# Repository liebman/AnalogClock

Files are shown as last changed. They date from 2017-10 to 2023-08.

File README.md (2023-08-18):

# AnalogClock 2.X

Project to sync analog clocks to a few milliseconds using NTP for time synchronization. Details of operation can be found in this [blog post](https://blog.taboola.com/analog-clocks-ntp/)



[I2CAnalogClock](I2CAnalogClock) contains the code for the ATTiny85 as an I2C based Analog Clock controller.  I am now using [PlatformIO](https://platformio.org/) for development.

[SynchroClock](SynchroClock) contains the code for the ESP8266 module.   I am now using [PlatformIO](https://platformio.org/) for development.

[NTPTest](NTPTest) contains a framework for testing the NTP class in an accelerated manor on linux or MacOS saving days of waiting for results.

[eagle](eagle) contains the [Eagle](https://www.autodesk.com/products/eagle/overview) design files and the BOM.

## Features

* Automatic daylight saving time adjustments
* Clock position & configuration saved on power fail
* Low power consumption: approx. 0.25ma in early testing
* adjustable tick/adjust pulse width/duty cycle/delay should support most one second "tick" (non-sweep) clocks.
* NTP implementation computes drift and uses that to increase accuricy between NTP updates

## Configuration

   When the clock is initially powered on it creates a wifi captive portal.  It will show up in the list of available wifi networks as SynchroClockXXXXXXX (where the X’s are some number).  Configuration mode can be forced by holding down the reset button until the LED is turns on and stays on for at least 2 seconds then releasing it. NOTE that if you conrinue holding the reset button for more than 10 seconds the LED will go back off initiating a factory reset to default settings. When you connect to this you are given a menu that lets you set many configuration options:

* Wifi Network (SSID)
* Wifi Network password
* Clock Position - enter the current time shown on the clock as HH:MM:SS.
* NTP Server to sync with
* 1st time change as 6 fields (US/Pacific would be: 2 0 0 3 2 -25200 meaning the second Sunday in March at 2am we change to UTC-7 hours, and Israel: -1 0 -2 3 2 10800 meaning the Friday before the last Sunday of in March at 2am we change to UTC+3)
  * occurrence - 2 would be the second occurrence of the day of week specified, -1 would be the last one.
  * day of week - where 0 = Sunday
  * days offset - +|- days, used for "the Friday before the last Sunday"
  * month - where 1 = January
  * hour - where 0 = midnight
  * time offset - this is the offset in seconds from UTC
* 2nd time change as 5 fields as described above (US/Pacific: 1 0 0 11 2 -28800 meaning the first Sunday in November at 2am we change to UTC-8 hours, and Israel: -1 0 0 10 2 7200 meaning the last Sunday of October we change to UTC-2)

Advanced options:

* Stay Awake - when set true the ESP8266 will not use deep sleep and will run a small web servers allowing various operations to be performed with an http interface.
* Tick Pulse - this is the duration in milliseconds of the “tick”.
* Tick Duty Cycle - the percentage of time that the tick is on using PWM
* Adjust Start Pulse - this uis the duration in milliseconds of the initial pulse of an adjustment
* Adjust Pulse - this is the duration in milliseconds of the “tick” used to advance the clock rapidly.
* Adjust Duty Cycle - the percentage of time that the tick is on using PWM
* Adjust Delay - this is the delay in milliseconds between “ticks” when advancing the clock rapidly.
* Network Logger Host - (optional) hostname to send log lines to.
* Network Logger Port - (optional) tcp port to send log lines to.
* Clear NTP Persist - when set 'true' clears any saved adjustments and drift calculations.

## Schematic

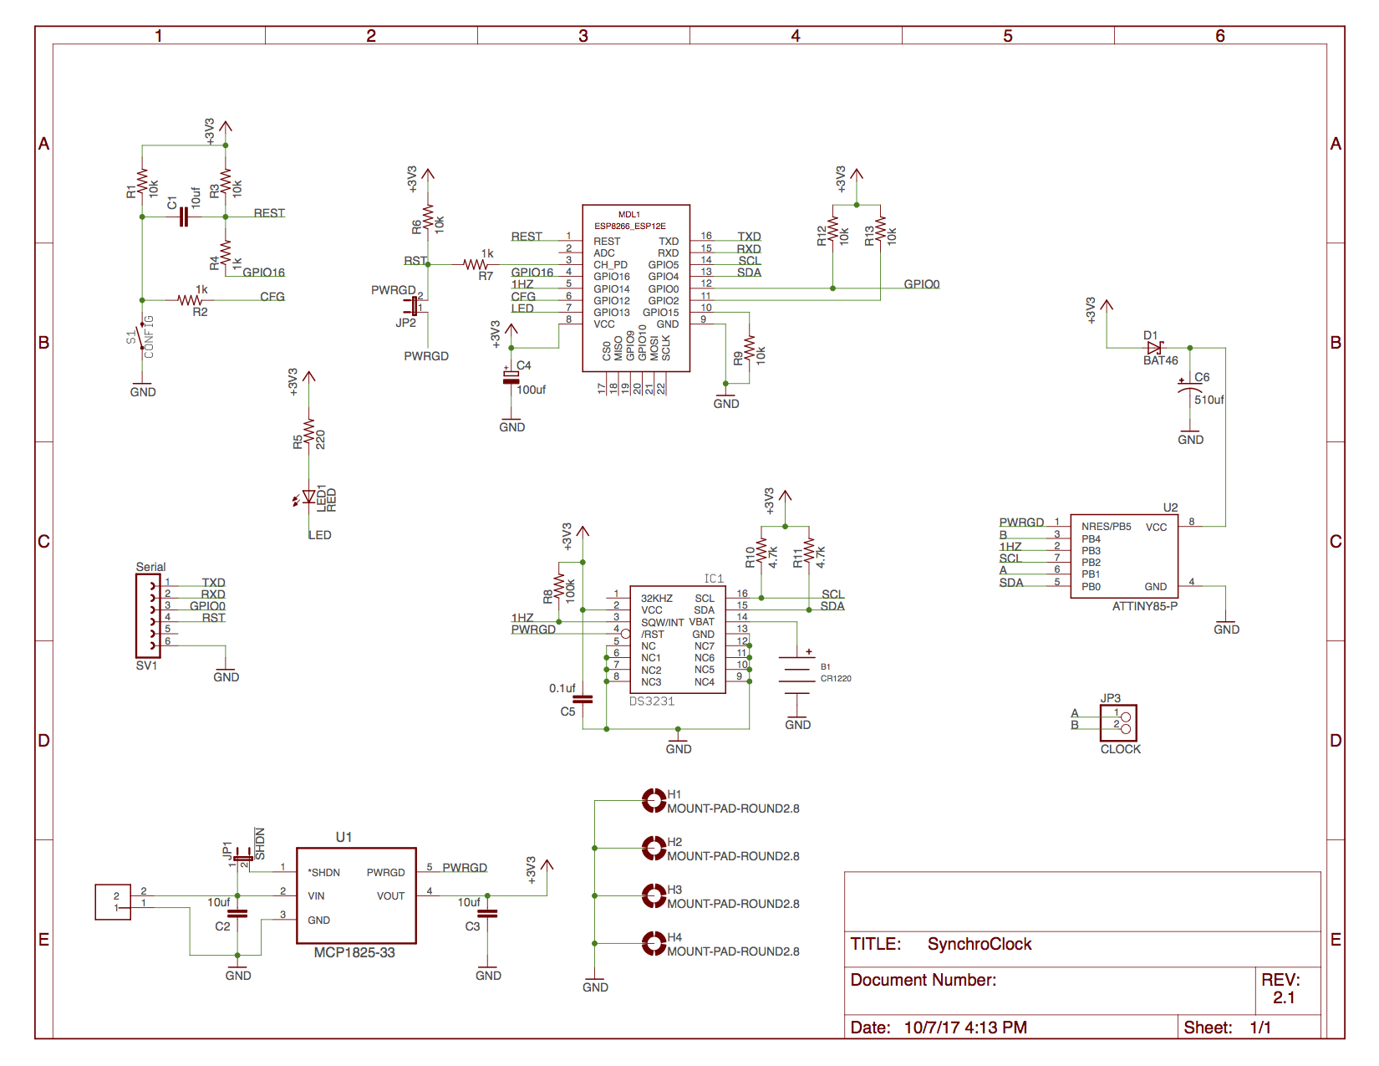
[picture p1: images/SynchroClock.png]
Schematic


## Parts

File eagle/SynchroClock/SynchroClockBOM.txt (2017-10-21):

Partlist exported from /Users/liebman/src/AnalogClock/eagle/SynchroClock/SynchroClock.sch at 10/7/17 9:38 AM

Part Value              Device                          Package                  Description                                             
B1   CR1220             CR1220-HOLDER                   HARWIN-CR1220                                                                    
C1   10uf               C5/2.5                          C5B2.5                   CAPACITOR                                               
C2   10uf               C5/2.5                          C5B2.5                   CAPACITOR                                               
C3   10uf               C5/2.5                          C5B2.5                   CAPACITOR                                               
C4   100uf              CPOL-EUE2.5-5                   E2,5-5                   POLARIZED CAPACITOR, European symbol                    
C5   0.1uf              C2.5/2                          C2.5-2                   CAPACITOR                                               
C6   510uf              CPOL-USE3.5-8                   E3,5-8                   POLARIZED CAPACITOR, American symbol                    
D1   BAT46              BAT46                           DO35-10                  Schottky Diode                                          
H1   MOUNT-PAD-ROUND2.8 MOUNT-PAD-ROUND2.8              2,8-PAD                  MOUNTING PAD, round                                     
H2   MOUNT-PAD-ROUND2.8 MOUNT-PAD-ROUND2.8              2,8-PAD                  MOUNTING PAD, round                                     
H3   MOUNT-PAD-ROUND2.8 MOUNT-PAD-ROUND2.8              2,8-PAD                  MOUNTING PAD, round                                     
H4   MOUNT-PAD-ROUND2.8 MOUNT-PAD-ROUND2.8              2,8-PAD                  MOUNTING PAD, round                                     
IC1  DS3231/SO          DS3231/SO                       SO16W                                                                            
J1   VIN                2_PIN_JST-XH                    2_PIN_JST-XH             Corrected for XH 2 pin                                  
JP1  !SHDN              JUMPER-2PTH                     1X02                     Jumper                                                  
JP2  PWRGD              JUMPER-2PTH                     1X02                     Jumper                                                  
JP3  CLOCK              PINHD-1X2                       1X02                     PIN HEADER                                              
LED1 RED                LED3MM                          LED3MM                   LED                                                     
MDL1 ESP12E             ESP8266-12EESP8266-ESP12E       ESP8266-ESP12E           ESP8266-12E with additional I/O and GPIO04/05 corrected 
R1   10k                R-US_0204/2V                    0204V                    RESISTOR, American symbol                               
R2   1k                 R-US_0204/2V                    0204V                    RESISTOR, American symbol                               
R3   10k                R-US_0204/2V                    0204V                    RESISTOR, American symbol                               
R4   1k                 R-US_0204/2V                    0204V                    RESISTOR, American symbol                               
R5   220                R-US_0204/2V                    0204V                    RESISTOR, American symbol                               
R6   10k                R-US_0204/2V                    0204V                    RESISTOR, American symbol                               
R7   1k                 R-US_0204/2V                    0204V                    RESISTOR, American symbol                               
R8   100k               R-US_0204/2V                    0204V                    RESISTOR, American symbol                               
R9   10k                R-US_0204/2V                    0204V                    RESISTOR, American symbol                               
R10  4.7k               R-US_0204/2V                    0204V                    RESISTOR, American symbol                               
R11  4.7k               R-US_0204/2V                    0204V                    RESISTOR, American symbol                               
R12  10k                R-US_0204/2V                    0204V                    RESISTOR, American symbol                               
R13  10k                R-US_0204/2V                    0204V                    RESISTOR, American symbol                               
S1   CONFIG             MOMENTARY-SWITCH-SPST-PTH-6.0MM TACTILE_SWITCH_PTH_6.0MM Momentary Switch (Pushbutton) - SPST                    
SV1  Serial             FE06-1                          FE06                     FEMALE HEADER                                           
U1   MCP1825-33         MCP1825-3302E/AT                TO170P482X1024X3124-5P   IC, LDO, ADJ, 500MA                                     
U2   ATTINY85-P         ATTINY85-P                      PDIP08_300MIL            ATMEL ATtiny 85

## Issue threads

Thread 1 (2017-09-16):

detect power fail and save clock position

liebman, 2017-09-16:
* possibly use DS3231 power fail detection/reset
* add CRC and write to EEPROM

liebman, 2017-09-18:
Implemented in "v2" branch

Closed 2017-09-18.

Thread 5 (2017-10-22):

Support clocks with "sweep" second hands

liebman, 2017-10-22:
Clocks with "sweep" second hands, at least the ones I looked at, are ticked at 16 times per second instead of just 1 time per second.  It would be nice to support these.  One potential issue is how much power this will require, it could drastically reduce battery life.

liebman, 2018-03-24:
Not going to happen, they can be implemented but there are two major drawbacks:
 - uses 16 times the power
 - can't be advanced fast enough would take 5 1/2 hours to advance 11 hours

Closed 2018-03-24.

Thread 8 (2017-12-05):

randomize port used for source of ntp requests

liebman, 2017-12-05:
Some router NAT implementations could be confused when multiple devices are using the same source port.

see: https://github.com/esp8266/Arduino/pull/3919

liebman, 2018-03-24:
Not really an issue, I think that's really a Router NAT implementation bug.

Closed 2018-03-24.

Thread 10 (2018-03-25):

Factory Reset

liebman, 2018-03-25:
Needs to:
 - stop clock
 - clear wifi and all settings
 - restart

Needs some type if visual feedback with LED.

Closed 2018-03-25.

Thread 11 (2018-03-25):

dont start config portal on no connect

liebman, 2018-03-25:
To save battery life if WiFi is unavailable don't start the config portal unless the the button is held after reset.  If the button is not pressed then just go back to sleep.

Closed 2018-03-25.

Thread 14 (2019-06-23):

Changes with ESP-12S Module

edmalho, 2019-06-23:
The 12S already has some pull-up resistors, specifically on the CH-PD, GPIO0 and GPIO15. It also lacks a 470 resistor in series on REST.
What modifications do I need to make?
I'm thinking of removing  the R9, R12 and R13. Good idea?

liebman, 2019-08-18:
Did you get a chance to try a 12S?  On a separate project I had issues with reset, or maybe CH-PD not behaving the same.  I'd love to hear if you made this work.

liebman, 2019-08-18:
Yes you can leave at least those three resistors off.  Don't forget to change the flash mode to DIO. It does however have issues with the reset circuit in that the reset button, at least as designed, does not function.  As a work around you will should be able remove power and apply power with the button pressed instead of reset.....

liebman, 2019-08-18:
I'm thinking that the reset issue (RST pin having zero effect) may be due to my modules being defective or fakes.  Will have to acquire some from another source.

liebman, 2019-09-27:
I've just ordered some different esp-12s's and I'll test them again.

edmalho, 2019-10-23:
Sorry for the very late response. i didn't build boards yet, my free time went out the window but i would love to ear something from you when you test it

liebman, 2019-10-26:
@edmalho OK - my new esp-12s modules work perfectly. So I'm assuming that the previous modules were fakes. So yes you should be able to leave those three resistors off.

Closed 2021-09-08.

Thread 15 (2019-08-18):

Clock time update after power fail with no WiFi

liebman, 2019-08-18:
If power returns when WiFi is not available the clock runs but time is not updated. It should be able to update to the tie tracked in the DS3231 even without WiFi for NTP.

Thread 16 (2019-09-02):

track time of last falling edge via interrupt

liebman, 2019-09-02:
This could eliminate waitFor(edge) and the millisecond offset from the last falling edge could be computed, reducing awake time by not having to wait for an edge multiple times.  Still would need to wait for the corrected second boundry to write the updated time to the ds3231.

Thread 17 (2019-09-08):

if a sample delay is > "mean+2*std dev" then don't use it in drift estimate

liebman, 2019-09-08:
~~Also the reach flag is 0 (no reaches last 8 polls) reset nsamples forcing.  That or some other method of dealing with a long term increase in latency.~~

Skipping outlying long delays should help eliminate big swings in estimated  drift if we get one or two long delay samples.

liebman, 2019-09-09:
A current working fix is to follow the same logic as when deciding if a given offset is good enough to update the clock where the delay value is within 1 standard deviation of the mean delay.  Fix committed.

Closed 2019-09-09.

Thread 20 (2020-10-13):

Hi!

winell28, 2020-10-13:
Hi liebman,

I absolutely love this idea. It is exactly what I have been looking for for my house.
Unfortunately creating something like this is a bit beyond my abilities and I was wondering how much it would be for you to build one for me? Obviously I would pay for all parts and chuck in a bit extra for your time, just curious.
Thank you

balzreber, 2023-08-17:
Hi winell28
I don't know if you are still interested in this project. If so, see https://github.com/liebman/AnalogClock/issues/24
I made a version you can order fully assembled. It will be published shortly.

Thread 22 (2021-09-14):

Support for silent clocks

kruton, 2021-09-14:
In your blog post you mentioned future work could include support for silent clocks. I went to IKEA and bought a clock and they all seem to be of the silent type. I hooked it up to an oscilloscope to see what it was outputting.

Could you provide any guidance on how to emulate this using the ATtiny85's PWM output and whether this will deplete the battery faster to wake up to do 8Hz ticks?

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

liebman, 2021-09-14:
I played with this and dropped it due to the excess battery drain.  It should work. Maybe using C or D cells can give long enough battery life.  You will have to play with it and see.  Rough calculation says it will use 8x the power.

liebman, 2021-09-14:
The other issue is setting the initial time.  With 1 hz its easy but with 8 power could drop out 4 "ticks" into a second..... so you will have to keep time in 8ths of a second, which may need changes in the protocol between the esp and the t85.

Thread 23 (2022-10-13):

Trying to reach you

JimDrewGH, 2022-10-13:
I hate to add an 'issue', but I know you can delete this... I have been trying to contact you directly for several months but I can not figure out an email for you so I am resorting to this method.  I left you a PM at www.esp32.com, please check your PM.  Thank you!  :)

liebman, 2022-10-13:
replied - closing

Closed 2022-10-13.

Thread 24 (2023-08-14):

SMD Version

balzreber, 2023-08-14:
Hello liebman

I'm currently in the final stages of finishing an SMD version of your awesome AnalogClock.
I only use JLCPCB components, so the board should be orderable from there, almost fully assembled.
The current version is a 1:1 replica of your design.
I think I could make the design even simpler, and therefore smaller. But I have some questions for you about that.
Of course, I will share my design once it is finished.

(Image is wip)
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

balzreber, 2023-08-17:
I finished the board. It's now 100% JLCPCB parts, including THT. So the board can be ordered fully assembled.
I got the footprint down to 70mm x 40mm.
I'm just waiting for a missing part to arrive at JLCPCB. As soon as that happens, I will place my order.
By now I pretty much found out what I needed to know by myself.
I plan to spit off my board into a separate reopo. I know I'm technicaly allowed to do that, due to this project running on an Apache 2.0 license. But it would be nice nevertheless to get an okay from liebman?! Maybe he could even reference my repo in the readme of this project?
I will create my repo after I'm able to get my board, so I can be sure that there are no errors.
I will post updates here until then.

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

liebman, 2023-08-17:
This looks really nice!  The only potential issue I see is programming the AtTiny85v, have you considered how your going to manage that? (will JLCPCB program them before assembly?)

balzreber, 2023-08-17:
Good point. My idea was to program it "in-circuit". Something like in the image below.
Or do you see any circuit limitation that would prevent this?

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

liebman, 2023-08-17:
It may work for the initial programming but after the fuses are set the reset pin will be disabled (its turned into a GPIO to detect power fail)

balzreber, 2023-08-17:
I see what you mean. I think I will add some dip switches to completely isolate the attiny85 just for programming. Thanks for your thoughts on this @liebman

balzreber, 2023-08-18:
That is a good idea. I didn't want to do that, so you can order the board fully assembled. And I don't think JLCPCB will socket the chip for me. Neither will they deliver it as a loose part. But since you need to order an Attiny programming board separately anyways, you may as well order the chip with that.
I will be back with a modified design.
Thank you so much for your help liebman. As you probably noticed, I'm not an electronics engineer ;-)

balzreber, 2023-08-18:
By the way, Is that okay with you @liebman ?

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

alteredz, 2023-08-18:
Once this board design is finalized, I'd like to purchase a couple.
I'd prefer getting them with the chip already programmed.
Thanks, Pete

liebman, 2023-08-18:
@balzreber I'm fine with that labeling.

Some assembly houses can pre-program MCUs as part of assembly, you may want to see if thats possible in this case.  If so then you can put some SMD jumpers on the traces that lead to the attiny, that way if you needed to re-program it a second time you could cut these, program, and then solder bridge the cut.

Also the one thing that I found most difficult was finding clock movements that were easy to modify - and tuning the exact pulse timing and pwm level was a real challenge. I'll look later to find where I ordered these from.

balzreber, 2023-08-18:
@alteredz I was talking to JLCPCB about that. They told me that they could theoretically do that. But they would have to look at the exact schematics to confirm. And of course, it costs extra. And since they have to involve some engineers, the markup will be significant!
I'm currently changing the design to have a socketed Attiny. You can then buy a USB programming adapter (like the one in the image a few posts further up) and program the Attiny with that. It should be pretty much plug-and-play.
Of course, you can talk to JLCPCB yourself, I didn't ask for the exact price. And of course, you can order the same board from other manufacturers. It's just that my BOM will have JLCPCB part numbers in it. So you would need to change that.

@liebman thanks for the hint! I'm living in Switzerland. The home of clocks. So I hope I can get some good clockworks here :-)) But I would appreciate you looking up which ones you used nevertheless ;-) Thanks

liebman, 2023-08-18:
I noticed that the blog link was broken - I've just updated it - it will provide a lot of info about the design. https://blog.taboola.com/analog-clocks-ntp/

liebman, 2023-08-18:
This is what I had the best success with https://www.klockit.com/all-departments/quartz-clock-movements/quartexr-push-on-quartz-clock-movement-threaded.html

balzreber, 2023-08-19:
@liebman Thanks for the additional info!

In the meantime, I modified the design to have a socketed Attiny85. Still waiting for the missing JLCPCB part.
I will keep you guys up to date on further progress.

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

liebman, 2023-08-19:
You should switch C4 to a multilayer ceramic one like [this](https://jlcpcb.com/partdetail/TaiyoYuden-JMK212BBJ107MGTE/C2880375)

balzreber, 2023-08-19:
Okay, will do that. You had an Alu as C4 in your assembly pics, that's why I have chosen one as well.

Those are the rest of the relevant components. I remember that I had to "upgrade" C6 to 680uF due to availability.
Do you mind having a look over those and tell me if you see any other problems?

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
Pretty much all standard 0805 250mW film resistors

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
The capacitors. Will change C4 to ceramic.

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
RTC

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
D2 Diode

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
Voltage Regulator. That's the one I'm waiting to arrive at JLCPCB

The Attiny is a Attiny85V-10PU like I read in your blog.

And sorry @liebman I didn't want to pull you in this so deep. But I totally don't mind if you are willing to help ;-)

liebman, 2023-08-19:
C2 - the one you have is 6.3V - thats cutting it close (4AA batteries is ~6v) I'd choose one with a higher voltage rating.

balzreber, 2023-08-19:
Will change that.
And thanks man, I really appreciate your help!

balzreber, 2023-08-20:
Alright. I updated the design again. C4 is now ceramic and C2 is 16V.

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
(I know the Attiny looks like a chip here. That's only the JLCPCB 3d model. It is a socket)

Still waiting for the Voltage Regulator to arrive.

balzreber, 2023-09-05:
I finally got the boards 🥳

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

ESP and Attiny are programmed. Worked like a charm.
The only thing is that the clock I connected is only jittering. But I guess, as @liebman said here https://github.com/liebman/AnalogClock/issues/24#issuecomment-1683946162, this is only a problem with the correct tick pulse and duty settings.
Otherwise, everything seems to work as planned so far.
I will make sure to post updates on any further progress.

balzreber, 2023-09-05:
Finally got the boards.

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

ESP and Attiny are programmed. Worked like a charm.
The only thing is that the clock I connected only jitters. But I guess this is only a problem with the correct tick pulse and duty cycle settings. As @liebman mentioned here https://github.com/liebman/AnalogClock/issues/24#issuecomment-1683946162
Otherwise, everything works as advertised.
I will make sure to post any further progress updates here.

balzreber, 2023-09-06:
I did some measuring today.

This is the clock movement I'm using <span>@</span>10ms / 500mV:
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

This is the output of the board (with default parameters) <span>@</span>10ms / 500mV:
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

And with higher resolution <span>@</span>500us / 1V:
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

@liebman Is it normal that the board output is not a single pulse like the clock itself? Or is there something wrong with the board?
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
balzreber, 2023-09-07:
I'm sorry. I know what you mean now.
You are only speaking of the duty setting which varies the output to the clock.
And you are right. The clock itself only uses one 1.5V cell.
The thing is, if I set the duty to 50 the clock handle only jitters. It starts moving at about 85.

liebman, 2023-09-07:
have you tried varying the pulse width?

balzreber, 2023-09-08:
I have done that. But I was only playing around with the values.
I will do a methodical test series with multiple clock movements today. I will post the results here.

In the meantime. I finally got the rsyslog to work.
And I noticed that the clock is unable to sync with NTP.
I always get:

...
2023-09-08T07:43:27.308976+02:00 esp-acd0de.local SynchroClock: 00acd0de 1.1.12-la[0]: 93.580266 I setup syncing RTC from NTP!
2023-09-08T07:43:27.325574+02:00 esp-acd0de.local SynchroClock: 00acd0de 1.1.12-la[0]: 93.596183 I setRTCfromNTP using server: 0.zoddotcom.pool.ntp.org
2023-09-08T07:43:27.958741+02:00 esp-acd0de.local SynchroClock: 00acd0de 1.1.12-la[0]: 94.227662 I NTP ::getOffset: NEW server: 0.zoddotcom.pool.ntp.org address: 156.106.214.48
2023-09-08T07:43:29.300346+02:00 esp-acd0de.local SynchroClock: 00acd0de 1.1.12-la[0]: 95.573045 E UDPWrapper ::recv: failed wanted:48 != size:0
2023-09-08T07:43:29.322768+02:00 esp-acd0de.local SynchroClock: 00acd0de 1.1.12-la[0]: 95.592012 I NTP ::makeRequest: used server: 0.zoddotcom.pool.ntp.org address: 156.106.214.48
2023-09-08T07:43:29.341810+02:00 esp-acd0de.local SynchroClock: 00acd0de 1.1.12-la[0]: 95.614876 I NTP ::makeRequest: packet size: 0
2023-09-08T07:43:29.358791+02:00 esp-acd0de.local SynchroClock: 00acd0de 1.1.12-la[0]: 95.631535 I NTP ::makeRequest: duration 1019ms
2023-09-08T07:43:29.372336+02:00 esp-acd0de.local SynchroClock: 00acd0de 1.1.12-la[0]: 95.648377 E NTP ::makeRequest: bad packet!
2023-09-08T07:43:29.392327+02:00 esp-acd0de.local SynchroClock: 00acd0de 1.1.12-la[0]: 95.664632 E NTP ::getOffset: makeRequest returns: -1
2023-09-08T07:43:29.406109+02:00 esp-acd0de.local SynchroClock: 00acd0de 1.1.12-la[0]: 95.682326 W setRTCfromNTP NTP Failed!
...

I tried multiple different NTP Servers. No luck.

liebman, 2023-09-08:
I was going to ask, but can't see it from the board pictures, did you put a keep-out zone under the ESP12's antenna?

balzreber, 2023-09-11:
I have done that, yes. The area under the antenna is where the label is.

Sorry I didn't post measurements yet. I got hung up on another project. But I will be back soon with more...

balzreber, 2023-11-24:
So I tested a. bunch of clock movements. Everything seems to work just fine. I can set the clock with no problems. With duty cycles around 90.

There are two problems remaining:

1.) The clock resets to captive portal once I recycle power. So I have to set the wifi every time I take the clock off power. But I think this is a software issue. Since all the parameters are saved on power loss. Or is this some strange reset happening because of hardware?

2.) I can't get the clocks to tick in unicent. They are around half a second off. Am I hitting the limits of the design, or is it possible to get the seconds closer?

What do you think @liebman?

liebman, 2023-12-02:
Sorry for the delay, I've been busy moving.  Are you still using a local NTP server?  Also it may take some time for the clocks to compensate for network latency - run them for a few days and see if the times don't sync better. I had 4 clocks all synced in an office I worked in previously.

balzreber, 2023-12-05:
No worries.
Yes, I'm still using a local NTP. But that shouldn't matter, right?

I'm currently building my third clock. As soon as that is finished, I will let them all run for some days and see what happens. Thanks for the advice!

What do you think about the wifi reconnecting problem? If that is indeed software, I think I can release the SMD board files. The rest seems to work like a charm.

liebman, 2023-12-05:
The wifi re-connect could be either - you will need to capture the serial output to analyze this.

balzreber, 2023-12-07:
Alright. I will do some more debugging.
You never had this problem? (Which would point more to a hardware issue).

liebman, 2023-12-07:
Not that I recall.

maxlyth, 2024-05-13:
@balzreber Did the SMD files get finalised? Your version of the repo seems empty.

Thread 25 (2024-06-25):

Is the PCB from OSHPark still current?

apadua, 2024-06-25:
I'm about to order it, but since the blog post is from 2019 I figured I'd check here first - is it worth ordering or should I look at making/building my own? Thanks so much!

liebman, 2024-06-26:
Yes - I've made no changes so they should still be current.
Another potential option is the SMD board [referenced here](https://github.com/liebman/AnalogClock/issues/24).

apadua, 2024-06-26:
The SMD board looks great but the repo is empty :-(

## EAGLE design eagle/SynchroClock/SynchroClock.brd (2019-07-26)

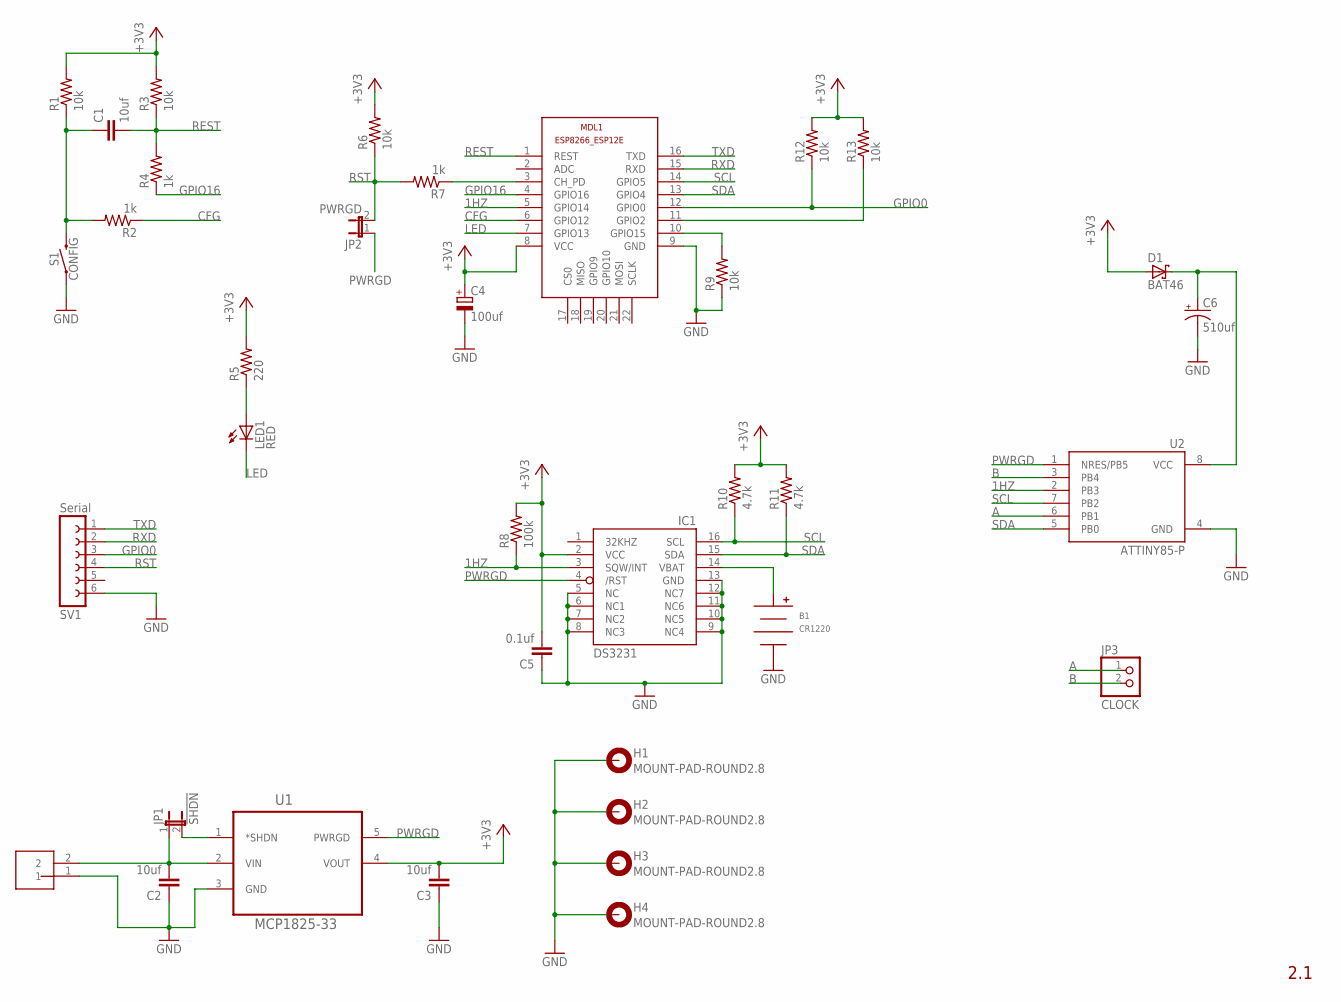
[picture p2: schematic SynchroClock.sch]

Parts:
B1: CR1220; HARWIN-CR1220
C1, C2, C3: 10uf; C5B2.5
C4: 100uf; E2,5-5
C5: 0.1uf; C2.5-2
C6: 510uf; E3,5-8
D1: BAT46; DO35-10
H1, H2, H3, H4: MOUNT-PAD-ROUND2.8; 2,8-PAD
IC1: DS3231/SO; SO16W
J1: VIN; 2_PIN_JST-XH
JP1: !SHDN; 1X02
JP2: PWRGD; 1X02
JP3: CLOCK; 1X02
LED1: RED; LED3MM
MDL1: ESP12E; ESP8266-ESP12E
R1, R3, R6, R9, R12, R13: 10k; 0204V
R2, R4, R7: 1k; 0204V
R5: 220; 0204V
R8: 100k; 0204V
R10, R11: 4.7k; 0204V
S1: CONFIG; TACTILE_SWITCH_PTH_6.0MM
SV1: Serial; FE06
U1: MCP1825-33; TO170P482X1024X3124-5P
U2: ATTINY85-P; PDIP08_300MIL

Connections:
1HZ: IC1.3 (SQW/INT), MDL1.5 (GPIO14), R8.1, U2.2 (PB3)
!SHDN: JP1.2, U1.1 (*SHDN)
+3V3: C3.2, C4.+, C5.2, D1.A, IC1.2 (VCC), MDL1.8 (VCC), R1.2, R3.2, R5.2, R6.2, R8.2, R10.2, R11.2, R12.2, R13.2, U1.4 (VOUT)
+5V: C2.2, J1.2, JP1.1, U1.2 (VIN)
A: JP3.1, U2.6 (PB1)
ATVCC: C6.+, D1.C, U2.8 (VCC)
B: JP3.2, U2.3 (PB4)
CFG: MDL1.6 (GPIO12), R2.1
CH_PD: MDL1.3 (CH_PD), R7.1
GND: B1.NEG, C2.1, C3.1, C4.-, C5.1, C6.-, H1.B2,8, H2.B2,8, H3.B2,8, H4.B2,8, IC1.5 (NC), IC1.6 (NC1), IC1.7 (NC2), IC1.8 (NC3), IC1.9 (NC4), IC1.10 (NC5), IC1.11 (NC6), IC1.12 (NC7), IC1.13 (GND), J1.1, MDL1.9 (GND), R9.1, S1.1, SV1.6, U1.3 (GND), U2.4 (GND)
GPIO0: MDL1.12 (GPIO0), R12.1, SV1.3
GPIO2: MDL1.11 (GPIO2), R13.1
GPIO15: MDL1.10 (GPIO15), R9.2
GPIO16: MDL1.4 (GPIO16), R4.1
LED: LED1.K (C), MDL1.7 (GPIO13)
unnamed: C1.1, R1.1, R2.2, S1.3 (2)
unnamed: LED1.A, R5.1
PWRGD: IC1.4 (/RST), JP2.1, U1.5 (PWRGD), U2.1 (NRES/PB5)
REST: C1.2, MDL1.1 (REST), R3.1, R4.2
RST: JP2.2, R6.1, R7.2, SV1.4
RXD: MDL1.15 (RXD), SV1.2
SCL: IC1.16 (SCL), MDL1.14 (GPIO5), R10.1, U2.7 (PB2)
SDA: IC1.15 (SDA), MDL1.13 (GPIO4), R11.1, U2.5 (PB0)
TXD: MDL1.16 (TXD), SV1.1
VBAT: B1.POS, IC1.14 (VBAT)

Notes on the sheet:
2.1

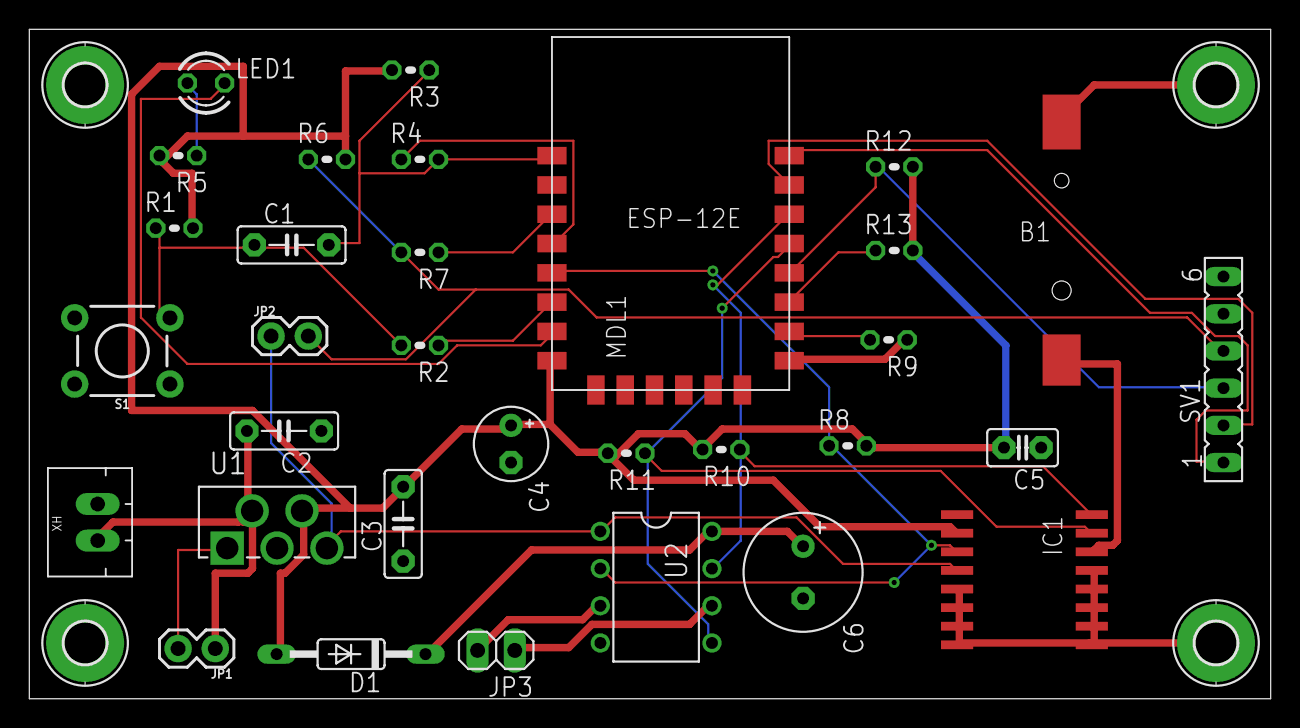
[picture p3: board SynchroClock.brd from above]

Board: 2 copper layers, 84.8 x 45.7 mm, 36 parts (0 on the bottom side), 25 nets.

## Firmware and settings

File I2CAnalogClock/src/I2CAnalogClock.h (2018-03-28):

/*
 * I2CAnalogClock.h
 *
 * Copyright 2017 Christopher B. Liebman
 *
 * Licensed under the Apache License, Version 2.0 (the "License");
 * you may not use this file except in compliance with the License.
 * You may obtain a copy of the License at
 *
 *     http://www.apache.org/licenses/LICENSE-2.0
 *
 * Unless required by applicable law or agreed to in writing, software
 * distributed under the License is distributed on an "AS IS" BASIS,
 * WITHOUT WARRANTIES OR CONDITIONS OF ANY KIND, either express or implied.
 * See the License for the specific language governing permissions and
 * limitations under the License.
 *
 *
 *  Created on: May 26, 2017
 *      Author: liebman
 */

#ifndef _I2CAnalogClock_H_
#define _I2CAnalogClock_H_
#include "Arduino.h"
#include "PinChangeInterrupt.h"
#include <avr/sleep.h>
#include "Wire.h"
#include "EEPROM.h"

#if !defined(__AVR_ATtinyX5__)
//#define DEBUG_I2CAC
//#define DEBUG_POSITION
#define SERIAL_BAUD     115200
#endif

//#define START_ENABLED
//#define SKIP_INITIAL_ADJUST
//#define TEST_MODE


#ifndef TEST_MODE
#define USE_SLEEP
#define USE_POWER_DOWN_MODE
#endif

#ifdef __AVR_ATtinyX5__
#ifdef TEST_MODE
#define LED_PIN         3
#else
#define INT_PIN         3
#endif
#define A_PIN           1
#define B_PIN           4
#define PWRFAIL_PIN     5
#else
#define INT_PIN         3
#define A_PIN           9
#define B_PIN           10
#define PWRFAIL_PIN     2
#define LED_PIN         LED_BUILTIN
#endif

#define TICK_ON         HIGH
#define TICK_OFF        LOW

#define MAX_SECONDS     43200


#define I2C_ADDRESS     0x09

#define CMD_ID          0x00
#define CMD_POSITION    0x01
#define CMD_ADJUSTMENT  0x02
#define CMD_CONTROL     0x03
#define CMD_STATUS      0x04
#define CMD_TP_DURATION 0x05
#define CMD_SAVE_CONFIG 0x06
#define CMD_AP_DURATION 0x07
#define CMD_AP_START    0x08
#define CMD_AP_DELAY    0x09
#define CMD_PWMTOP      0x0a
#define CMD_TP_DUTY     0x0b
#define CMD_AP_DUTY     0x0c
#define CMD_RESET       0x0d
#define CMD_RST_REASON  0x0e
#define CMD_VERSION     0x0f

// control register bits
#define BIT_ENABLE      0x80

// status register bits
#define STATUS_BIT_TICK    0x01
#define STATUS_BIT_PWFBAD  0x80

#define ID_VALUE        0x42

#define isEnabled()     (control &  BIT_ENABLE)

#define isTick()        (status &  STATUS_BIT_TICK)
#define toggleTick()    (status ^= STATUS_BIT_TICK)

//
// Timing defaults
//


#if defined(__AVR_ATtinyX5__)
#if F_CPU == 1000000L
#define PWM_PRESCALE      1
#define PWM_TOP           250 // 4khz
#define PWM_PRESCALE_BITS (_BV(CS10))
#elif F_CPU == 8000000L
#define PWM_PRESCALE      8
#define PWM_TOP           250 // 4khz
#define PWM_PRESCALE_BITS (_BV(CS12))
#endif
#else
#define PWM_TOP           250 // assuming 16mhz CPU its 8khz
#define PWM_PRESCALE      8
#define PWM_PRESCALE_BITS (_BV(CS11))
#endif

#define ms2PWMCount(x)    (F_CPU / PWM_PRESCALE / config.pwm_top / (1000.0 / (double)(x)))
#define duty2pwm(x)       ((x)*config.pwm_top/100)

#ifdef __AVR_ATtinyX5__
#if F_CPU == 8000000L
#define PRESCALE        4096
#define PRESCALE_BITS   ((1 << CS13) | (1 << CS12) | (1 <<CS10)) // 4096 prescaler
#elif F_CPU == 4000000L
#define PRESCALE        2048
#define PRESCALE_BITS   ((1 << CS13) | (1 << CS12)) // 2048 prescaler
#elif F_CPU == 1000000L
#define PRESCALE        512
#define PRESCALE_BITS   ((1 << CS13) | (1 << CS11)) // 512 prescaler
#endif
#define ms2Timer(x) ((uint8_t)(F_CPU /(PRESCALE * (1/((double)x/1000)))))
#else
#define PRESCALE        256
#define PRESCALE_BITS   (1 << CS12) // 256 prescaler
#define ms2Timer(x) ((uint16_t)(F_CPU /(PRESCALE * (1/((double)x/1000)))))
#endif

#define DEFAULT_TP_DURATION_MS 32  // pulse duration in ms.
#define DEFAULT_TP_DUTY        43  // duty cycle %.
#define DEFAULT_AP_START_MS    34  // initial adjust pulse duration
#define DEFAULT_AP_DURATION_MS 17  // pulse duration during adjust
#define DEFAULT_AP_DUTY        45  // duty cycle %.
#define DEFAULT_AP_DELAY_MS    9   // delay between adjust pulses in ms.

typedef struct config
{
    volatile uint8_t tp_duration;
    volatile uint8_t tp_duty;
    volatile uint8_t ap_duration;
    volatile uint8_t ap_duty;
    volatile uint8_t ap_delay;          // delay in ms between ticks during adjustment
    volatile uint8_t ap_start_duration; // duration of the first tick
    volatile uint8_t pwm_top;
} Config;

typedef struct ee_config
{
    uint32_t crc;
    uint8_t data[sizeof(Config)];
} EEConfig;

typedef struct power_fail_data
{
    uint16_t position;
    uint8_t  control;
    uint8_t  status;
} PowerFailData;

typedef struct ee_power_fail_data
{
    uint32_t      crc;
    PowerFailData data;
} EEPowerFailData;

#define CONFIG_ADDRESS     0
#define POWER_FAIL_ADDRESS sizeof(EEConfig)

void startAdjust();
void adjustClock();
void advanceClock(uint16_t duration, uint8_t duty);
void tick();

uint32_t calculateCRC32(const uint8_t *data, size_t length);
void clearConfig();
boolean loadConfig();
void saveConfig();

#if defined(PWRFAIL_PIN)
void clearPowerFailData();
boolean loadPowerFailData();
void savePowerFailData();
#endif

#endif /* _I2CAnalogClock_H_ */

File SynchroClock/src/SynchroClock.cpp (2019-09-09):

/*
 * SynchroClock.cpp
 *
 * Copyright 2017 Christopher B. Liebman
 *
 * Licensed under the Apache License, Version 2.0 (the "License");
 * you may not use this file except in compliance with the License.
 * You may obtain a copy of the License at
 *
 *     http://www.apache.org/licenses/LICENSE-2.0
 *
 * Unless required by applicable law or agreed to in writing, software
 * distributed under the License is distributed on an "AS IS" BASIS,
 * WITHOUT WARRANTIES OR CONDITIONS OF ANY KIND, either express or implied.
 * See the License for the specific language governing permissions and
 * limitations under the License.
 *
 *
 *  Created on: May 26, 2017
 *      Author: liebman
 */

#include "SynchroClock.h"
#include "SynchroClockVersion.h"
#include <FS.h>
#include <time.h>
#include <sys/time.h>
#include <lwip/apps/sntp.h>
#include <umm_malloc/umm_malloc.h>

//
// These are only used when debugging
//
//#define DISABLE_DEEP_SLEEP
//#define DISABLE_INITIAL_NTP
//#define DISABLE_INITIAL_SYNC

DLog&            dlog = DLog::getLog();
Config           config;                    // configuration persisted in the EEPROM
DeepSleepData    dsd;                       // data persisted in the RTC memory
#if defined(LED_PIN)
FeedbackLED      feedback(LED_PIN);         // used to blink LED to indicate status
#endif
ESP8266WebServer HTTP(80);                  // used when debugging/stay awake mode
NTP              ntp(&(dsd.ntp_runtime), &(config.ntp_persist), &saveConfig);   // handles NTP communication & filtering
Clock            clk(SYNC_PIN);             // clock ticker, manages position of clock
DS3231           rtc;                       // real time clock on i2c interface

boolean save_config  = false; // used by wifi manager when settings were updated.
boolean force_config = false; // reset handler sets this to force into config mode if button held
boolean stay_awake   = false; // don't use deep sleep (from config mode option)
boolean url_update   = false; // set true of we got an update url

char devicename[32];

char message[128]; // buffer for http return values

#ifdef USE_CERT_STORE
BearSSL::CertStore certStore;
#endif

boolean parseBoolean(const char* value)
{
    if (!strcmp(value, "true") || !strcmp(value, "True") || !strcmp(value, "TRUE") || atoi(value))
    {
        return true;
    }
    return false;
}

uint8_t parseDuty(const char* value)
{
    int i = atoi(value);
    if (i < 1 || i > 100)
    {
        dlog.error(F("parseDuty"), F("invalid value %s: using 50 instead!"), value);
        i = 50;
    }
    return (uint8_t) i;
}

int getValidOffset(String name)
{
    int result = TimeUtils::parseOffset(HTTP.arg(name).c_str());

    return result;
}

uint16_t getValidPosition(String name)
{
    int result = TimeUtils::parsePosition(HTTP.arg(name).c_str());

    return result;
}

uint8_t getValidDuration(String name)
{
    uint8_t result = TimeUtils::parseSmallDuration(HTTP.arg(name).c_str());
    return result;
}

uint8_t getValidDuty(String name)
{
    uint8_t result = parseDuty(HTTP.arg(name).c_str());
    return result;
}

boolean getValidBoolean(String name)
{
    boolean result = parseBoolean(HTTP.arg(name).c_str());
    return result;
}

uint8_t getValidByte(String name)
{
    int i = atoi(HTTP.arg(name).c_str());
    if (i < 0 || i > 255)
    {
        dlog.error(F("getValidByte"), F("invalid value %d: using 255 instead!"), i);
        i = 255;
    }
    return (uint8_t) i;
}

void handleOffset()
{
    if (HTTP.hasArg("set"))
    {
        config.tz_offset = getValidOffset("set");
        dlog.info(F("handleOffset"), F("seconds offset:%d"), config.tz_offset);
    }

    HTTP.send(200, "text/plain", String(config.tz_offset) + "\n");
}

void handleAdjustment()
{
    static PROGMEM const char TAG[] = "handleAdjustment";
    uint16_t adj;
    if (HTTP.hasArg("set"))
    {
        if (HTTP.arg("set").equalsIgnoreCase("auto"))
        {
            dlog.info(FPSTR(TAG), F("Auto Adjust!"));
            setCLKfromRTC();
        }
        else
        {
            adj = getValidPosition("set");
            dlog.info(FPSTR(TAG), F("setting adjustment:%u"), adj);
            if (clk.writeAdjustment(adj))
            {
                dlog.error(FPSTR(TAG), F("failed to set adjustment!"));
            }
        }
    }

    if (clk.readAdjustment(&adj))
    {
        sprintf_P(message, PSTR("failed to read adjustment!\n"));
    }
    else
    {
        sprintf_P(message, PSTR("adjustment: %d\n"), adj);
    }

    HTTP.send(200, "text/plain", message);
}

void handlePosition()
{
    static PROGMEM const char TAG[] = "handlePosition";

    uint16_t pos;
    if (HTTP.hasArg("set"))
    {
        pos = getValidPosition("set");
        dlog.info(FPSTR(TAG), F("setting position:%u"), pos);
        if (clk.writePosition(pos))
        {
            dlog.error(FPSTR(TAG), F("failed to set position!"));
        }
    }

    if (clk.readPosition(&pos))
    {
        sprintf_P(message, PSTR("failed to read position!\n"));
    }
    else
    {
        int hours = pos / 3600;
        int minutes = (pos - (hours * 3600)) / 60;
        int seconds = pos - (hours * 3600) - (minutes * 60);
        sprintf_P(message, PSTR("position: %d (%02d:%02d:%02d)\n"), pos, hours, minutes, seconds);
    }

    HTTP.send(200, "text/Plain", message);
}

void handleTPDuration()
{
    static PROGMEM const char TAG[] = "handleTPDuration";

    uint8_t value;
    if (HTTP.hasArg("set"))
    {
        value = getValidDuration("set");
        dlog.info(FPSTR(TAG), F("setting tp_duration:%u"), value);
        if (clk.writeTPDuration(value))
        {
            dlog.error(FPSTR(TAG), F("failed to set TP duration!"));
        }
    }

    if (clk.readTPDuration(&value))
    {
        sprintf_P(message, PSTR("failed to read TP duration\n"));
    }
    else
    {
        sprintf_P(message, PSTR("TP duration: %u\n"), value);
    }

    HTTP.send(200, "text/plain", message);
}

void handleTPDuty()
{
    static PROGMEM const char TAG[] = "handleTPDuty";
    uint8_t value;
    if (HTTP.hasArg("set"))
    {
        value = getValidDuty("set");
        dlog.info(FPSTR(TAG), F("setting tp_duty:%u"), value);
        if (clk.writeTPDuty(value))
        {
            dlog.error(FPSTR(TAG), F("failed to set TP duty!"));
        }
    }

    if (clk.readTPDuty(&value))
    {
        sprintf_P(message, PSTR("failed to read TP duty\n"));
    }
    else
    {
        sprintf_P(message, PSTR("TP duty: %u\n"), value);
    }

    HTTP.send(200, "text/plain", message);
}

void handleAPDuration()
{
    static PROGMEM const char TAG[] = "handleAPDuration";
    uint8_t value;
    if (HTTP.hasArg("set"))
    {
        value = getValidDuration("set");
        dlog.info(FPSTR(TAG), F("setting ap_duration:%u"), value);
        if (clk.writeAPDuration(value))
        {
            dlog.error(FPSTR(TAG), F("failed to set AP duration"));
        }
    }

    if (clk.readAPDuration(&value))
    {
        sprintf_P(message, PSTR("failed to read AP duration\n"));
    }
    else
    {
        sprintf_P(message, PSTR("AP duration: %u\n"), value);
    }

    HTTP.send(200, "text/plain", message);
}

void handleAPDuty()
{
    static PROGMEM const char TAG[] = "handleAPDuty";
    uint8_t value;
    if (HTTP.hasArg("set"))
    {
        value = getValidDuty("set");
        dlog.info(FPSTR(TAG), F("setting ap_duty:%u"), value);
        if (clk.writeAPDuty(value))
        {
            dlog.error(FPSTR(TAG), F("failed to set AP duty!"));
        }
    }

    if (clk.readAPDuty(&value))
    {
        sprintf_P(message, PSTR("failed to read AP duty\n"));
    }
    else
    {
        sprintf_P(message, PSTR("AP duty: %u\n"), value);
    }

    HTTP.send(200, "text/plain", message);
}

void handleAPDelay()
{
    static PROGMEM const char TAG[] = "handleAPDelay";
    uint8_t value;
    if (HTTP.hasArg("set"))
    {
        value = getValidDuration("set");
        dlog.info(FPSTR(TAG), F("setting ap_delay:%u"), value);
        if (clk.writeAPDelay(value))
        {
            dlog.error(FPSTR(TAG), F("failed to set AP delay"));
        }
    }

    if (clk.readAPDelay(&value))
    {
        sprintf_P(message, PSTR("failed to read AP delay\n"));
    }
    else
    {
        sprintf_P(message, PSTR("AP delay: %u\n"), value);
    }

    HTTP.send(200, "text/plain", message);
}

void handleAPStartDuration()
{
    static PROGMEM const char TAG[] = "handleAPStartDuration";
    uint8_t value;
    if (HTTP.hasArg("set"))
    {
        value = getValidDuration("set");
        dlog.info(FPSTR(TAG), F("setting ap_start:%u"), value);
        if (clk.writeAPStartDuration(value))
        {
            dlog.error(FPSTR(TAG), F("failed to set AP start duration"));
        }
    }

    if (clk.readAPStartDuration(&value))
    {
        sprintf_P(message, PSTR("failed to read AP start duration\n"));
    }
    else
    {
        sprintf_P(message, PSTR("AP start duration: %u\n"), value);
    }

    HTTP.send(200, "text/plain", message);
}

void handlePWMTop()
{
    static PROGMEM const char TAG[] = "handlePWMTop";
    uint8_t value;
    if (HTTP.hasArg("set"))
    {
        value = getValidByte("set");
        dlog.info(FPSTR(TAG), F("setting pwm_top:%u"), value);
        if (clk.writePWMTop(value))
        {
            dlog.error(FPSTR(TAG), F("failed to set pwm_top!"));
        }
    }

    if (clk.readPWMTop(&value))
    {
        sprintf_P(message, PSTR("failed to read pwm_top!\n"));
    }
    else
    {
        sprintf_P(message, PSTR("pwm_top: %u\n"), value);
    }

    HTTP.send(200, "text/plain", message);
}

void handleEnable()
{
    boolean enable;
    if (HTTP.hasArg("set"))
    {
        enable = getValidBoolean("set");
        clk.setEnable(enable);
    }
    enable = clk.getEnable();
    HTTP.send(200, "text/Plain", String(enable) + "\n");
}

void handleRTC()
{
    static PROGMEM const char TAG[] = "handleRTC";
    char message[64];

    DS3231DateTime dt;
    int err = rtc.readTime(dt);

    if (!err)
    {
        dlog.info(FPSTR(TAG), F("handleRTC: RTC : %s (UTC)"), dt.string());

        if (HTTP.hasArg("offset"))
        {
            double offset = strtod(HTTP.arg("offset").c_str(), NULL);
            dlog.info(FPSTR(TAG), F("handleRTC: offset: %lf"), offset);
            setRTCfromOffset(offset, true);
        }
        else if (HTTP.hasArg("sync") && getValidBoolean("sync"))
        {
            setCLKfromRTC();
        }

        uint16_t value = dt.getPosition(config.tz_offset);

        int hours = value / 3600;
        int minutes = (value - (hours * 3600)) / 60;
        int seconds = value - (hours * 3600) - (minutes * 60);
        sprintf_P(message, PSTR("%d (%02d:%02d:%02d)\n"), value, hours, minutes, seconds);
    }
    else
    {
        sprintf_P(message, PSTR("rtc.readTime() failed!\n"));
    }

    HTTP.send(200, "text/plain", message);
}

void handleNTP()
{
    static PROGMEM const char TAG[] = "handleNTP";
    char server[64];
    strcpy(server, config.ntp_server);
    boolean sync = false;

    if (HTTP.hasArg("server"))
    {
        dlog.info(FPSTR(TAG), F("SERVER: %s"), HTTP.arg("server").c_str());
        strncpy(server, HTTP.arg("server").c_str(), 63);
        server[63] = 0;
    }

    if (HTTP.hasArg("sync"))
    {
        sync = getValidBoolean("sync");
    }

    double offset;
    IPAddress address;
    char message[64];
    int code;
    if (setRTCfromNTP(server, sync, &offset, &address))
    {
        code = 500;
        snprintf_P(message, 64, PSTR("NTP Failed!\n"));
    }
    else
    {
        if (sync)
        {
            dlog.info(FPSTR(TAG), F("Syncing clock to RTC!"));
            setCLKfromRTC();
        }
        code = 200;

        snprintf_P(message, 64, PSTR("OFFSET: %0.6lf (%s)\n"), offset, address.toString().c_str());
    }

    dlog.info(FPSTR(TAG), F("%s"), message);
    HTTP.send(code, "text/Plain", message);
    return;
}

void handleWire()
{
    int rtn = WireUtils.clearBus();
    if (rtn != 0)
    {
        if (rtn == 1)
        {
            snprintf_P(message, 64, PSTR("SCL clock line held low\n"));
        }
        else if (rtn == 2)
        {
            snprintf_P(message, 64, PSTR("SCL clock line held low by slave clock stretch\n"));
        }
        else if (rtn == 3)
        {
            snprintf_P(message, 64, PSTR("SDA data line held low\n"));
        }
        else
        {
            snprintf_P(message, 64, PSTR("I2C bus error. Could not clear\n"));
        }
    }
    else
    {
        snprintf_P(message, 64, PSTR("Recovered!\n"));
    }

    HTTP.send(200, "text/Plain", message);
}

void handleSave()
{
    clk.saveConfig();
    saveConfig();
    HTTP.send(200, "text/plain", "Saved!\n");
}

void handleErase()
{
    eraseConfig();
    HTTP.send(200, "text/plain", "Erased!\n");
}
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
void loop()
{
    if (stay_awake)
    {
        HTTP.handleClient();
    }
    delay(100);
}

int getEdgeSyncedTime(DS3231DateTime& dt, unsigned int retries)
{
    static PROGMEM const char TAG[] = "getEdgeSyncedTime";
    clk.waitForEdge(CLOCK_EDGE_FALLING);

    while(retries-- > 0)
    {
        clk.waitForEdge(CLOCK_EDGE_FALLING);
        // need 1ms delay!  but why?  noise?
        delay(1);
        if (rtc.readTime(dt) == 0)
        {
            return 0;
        }

        dlog.warning(FPSTR(TAG), F("failed to read from RTC, %d retries left"), retries);
        WireUtils.clearBus();
    }
    return -1;
}

int setRTCfromOffset(double offset, bool sync)
{
    static PROGMEM const char TAG[] = "setRTCfromOffset";

    int32_t  seconds = (int32_t)offset;
    uint32_t msdelay = fabs((offset - (double)seconds) * 1000);

    if (offset > 0)
    {
        seconds = seconds + 1; // +1 because we go to the next second
        msdelay = 1000.0 - msdelay;
    }

    dlog.info(FPSTR(TAG), F("offset: %lf seconds: %d msdelay: %d sync: %s"),
            offset, seconds, msdelay, sync ? "true" : "false");

    DS3231DateTime dt;

    if (getEdgeSyncedTime(dt, 3))
    {
        dlog.error(FPSTR(TAG), F("failed to read from RTC!"));
        return ERROR_RTC;
    }

    // wait for where the next second should start
    if (msdelay > 0 && msdelay < 1000)
    {
        delay(msdelay);
    }

    uint32_t old_time = dt.getUnixTime();
    uint32_t new_time = old_time + seconds;
    dt.setUnixTime(new_time);

    if (sync)
    {
        if (rtc.writeTime(dt))
        {
            dlog.error(FPSTR(TAG), F("FAILED to set RTC: %s"), dt.string());
            return ERROR_RTC;
        }
    }

    //
    // Update the TZ offset in case the timezone offset has changed based on new time.
    //
    delay(1); // DS3231 seems to need a short delay after write before we read the time back
    updateTZOffset();

    dlog.info(FPSTR(TAG), F("old_time: %d new_time: %d"), old_time, new_time);
    dlog.info(FPSTR(TAG), F("RTC: %s"), dt.string());
    return 0;
}

/*
 * sync to a second boundary and return the current time in seconds
 */
int getTime(uint32_t *result)
{
    clk.waitForEdge(CLOCK_EDGE_FALLING);
    delay(2); // ATtiny85 at 1mhz has interrupts disabled for a bit after the falling edge
    DS3231DateTime dt;
    if (rtc.readTime(dt))
    {
        dlog.error(F("getTime"), F("failed to read from RTC!"));
        return -1;
    }
    *result = dt.getUnixTime();
    return 0;
}

int setRTCfromDrift()
{
    static PROGMEM const char TAG[] = "setRTCfromDrift";
    double offset;
    if (ntp.getOffsetUsingDrift(&offset, &getTime))
    {
        dlog.error(FPSTR(TAG), F("failed, not adjusting for drift!"));
        return -1;
    }

    dlog.info(FPSTR(TAG), F("********* DRIFT OFFSET: %lf"), offset);

    int error = setRTCfromOffset(offset, true);
    if (error)
    {
        return error;
    }

    dlog.debug(FPSTR(TAG), F("returning OK"));
    return 0;
}

int setRTCfromNTP(const char* server, bool sync, double* result_offset, IPAddress* result_address)
{
    static PROGMEM const char TAG[] = "setRTCfromNTP";

    dlog.info(FPSTR(TAG), F("using server: %s"), server);

    double offset;
    if (ntp.getOffset(server, &offset, &getTime))
    {
        dlog.warning(FPSTR(TAG), F("NTP Failed!"));
        return ERROR_NTP;
    }

    if (result_address)
    {
        *result_address = ntp.getAddress();
    }

    if (result_offset != NULL)
    {
        *result_offset = offset;
    }

    dlog.info(FPSTR(TAG), F("********* NTP OFFSET: %lf"), offset);

    int error = setRTCfromOffset(offset, sync);
    if (error)
    {
        return error;
    }

    dlog.debug(FPSTR(TAG), F("returning OK"));
    return 0;
}

int setCLKfromRTC()
{
    static PROGMEM const char TAG[] = "setCLKfromRTC";

    // if there is already an adjustment in progress then stop it.
    if (clk.writeAdjustment(0))
    {
        dlog.error(FPSTR(TAG), F("failed to clear adjustment!"));
        return -1;
    }

#if defined(USE_STOP_THE_CLOCK)
    int delta;
    uint16_t clock_pos;
    uint16_t rtc_pos;
    do
    {
        clk.waitForEdge(CLOCK_EDGE_FALLING);
        delay(10);

        if (clk.readPosition(&clock_pos))
        {
            dlog.error(FPSTR(TAG), F("failed to read position, ignoring"));
            return -1;
        }
        dlog.info(FPSTR(TAG), F("clock position:%d"), clock_pos);

        DS3231DateTime dt;
        if (rtc.readTime(dt))
        {
            dlog.error(FPSTR(TAG), F("FAILED to read RTC"));
            return -1;
        }
        rtc_pos = dt.getPosition(config.tz_offset);
        dlog.info(FPSTR(TAG), F("RTC position:%d"), rtc_pos);

        delta = rtc_pos - clock_pos;
        if (delta < 0 && abs(delta) < STOP_THE_CLOCK_MAX)
        {
            int stop_for = abs(delta) + STOP_THE_CLOCK_EXTRA;
            dlog.info(FPSTR(TAG), F("stop the clock delta is %d stopping for %d seconds"), delta, stop_for);

            // stop the clock for delta seconds
            clk.setEnable(false);
            delay(stop_for * 1000);
            clk.setEnable(true);
        }
        //
        // if we stopped the clock then repeat block to re-read clock & RTC
        //
    } while (delta < 0 && abs(delta) < STOP_THE_CLOCK_MAX);
#else
    clk.waitForEdge(CLOCK_EDGE_FALLING);
    delay(10);
    uint16_t clock_pos;
    if (clk.readPosition(&clock_pos))
    {
        dlog.error(FPSTR(TAG), F("failed to read position, ignoring"));
        return -1;
    }
    dlog.info(FPSTR(TAG), F("clock position:%d"), clock_pos);

    DS3231DateTime dt;
    if (rtc.readTime(dt))
    {
        dlog.error(FPSTR(TAG), F("FAILED to read RTC"));
        return -1;
    }
    uint16_t rtc_pos = dt.getPosition(config.tz_offset);
    dlog.info(FPSTR(TAG), F("RTC position:%d"), rtc_pos);
#endif

    if (clock_pos != rtc_pos)
    {
        int adj = rtc_pos - clock_pos;
        if (adj < 0)
        {
            adj += MAX_POSITION;
        }
        dlog.info(FPSTR(TAG), F("sending adjustment of %u"), adj);
        clk.waitForEdge(CLOCK_EDGE_RISING);
        if (clk.writeAdjustment(adj))
        {
            dlog.error(FPSTR(TAG), F("failed to set adjustment!"));
            return -1;
        }
    }

    return 0;
}

uint32_t calculateCRC32(const uint8_t *data, size_t length)
{
    uint32_t crc = 0xffffffff;
    while (length--)
    {
        uint8_t c = *data++;
        for (uint32_t i = 0x80; i > 0; i >>= 1)
        {
            bool bit = crc & 0x80000000;
            if (c & i)
            {
                bit = !bit;
            }
            crc <<= 1;
            if (bit)
            {
                crc ^= 0x04c11db7;
            }
        }
    }
    return crc;
}

void initConfig()
{
    if (EEPROM.length() != sizeof(EEConfig))
    {
        dlog.info(F("initConfig"), F("initializing EEPROM"));
        EEPROM.begin(sizeof(EEConfig));
    }
}

boolean loadConfig()
{
    static PROGMEM const char TAG[] = "loadConfig";
    EEConfig cfg;
    initConfig();
    // Read struct from EEPROM
    dlog.debug(FPSTR(TAG), F("loading from EEPROM"));
    unsigned int i;
    uint8_t* p = (uint8_t*) &cfg;
    for (i = 0; i < sizeof(cfg); ++i)
    {
        p[i] = EEPROM.read(i);
    }
    dlog.debug(FPSTR(TAG), F("checking CRC"));
    uint32_t crcOfData = calculateCRC32(((uint8_t*) &cfg.data), sizeof(cfg.data));
    dlog.trace(FPSTR(TAG), F("CRC32 of data: %08x"), crcOfData);
    dlog.trace(FPSTR(TAG), F("CRC32 read from EEPROM: %08x"), cfg.crc);
    if (crcOfData != cfg.crc)
    {
        dlog.warning(FPSTR(TAG), F("CRC32 in EEPROM memory doesn't match CRC32 of data. Data is probably invalid!"));
        return false;
    }
    dlog.debug(FPSTR(TAG), F("CRC32 check ok, data is probably valid."));
    memcpy(&config, &cfg.data, sizeof(config));
    return true;
}

void saveConfig()
{
    static PROGMEM const char TAG[] = "saveConfig";
    EEConfig cfg;
    initConfig();
    memcpy(&cfg.data, &config, sizeof(cfg.data));
    cfg.crc = calculateCRC32(((uint8_t*) &cfg.data), sizeof(cfg.data));
    dlog.debug(FPSTR(TAG), F("caculated CRC: %08x"), cfg.crc);
    dlog.info(FPSTR(TAG), F("Saving configuration to EEPROM!"));

    unsigned int i;
    uint8_t* p = (uint8_t*) &cfg;
    for (i = 0; i < sizeof(cfg); ++i)
    {
        EEPROM.write(i, p[i]);
    }
    bool result = EEPROM.commit();
    dlog.info(FPSTR(TAG), F("result: %s"), result ? "success" : "FAILURE");
}
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

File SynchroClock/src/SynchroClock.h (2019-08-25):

/*
 * SynchroClock.h
 *
 * Copyright 2017 Christopher B. Liebman
 *
 * Licensed under the Apache License, Version 2.0 (the "License");
 * you may not use this file except in compliance with the License.
 * You may obtain a copy of the License at
 *
 *     http://www.apache.org/licenses/LICENSE-2.0
 *
 * Unless required by applicable law or agreed to in writing, software
 * distributed under the License is distributed on an "AS IS" BASIS,
 * WITHOUT WARRANTIES OR CONDITIONS OF ANY KIND, either express or implied.
 * See the License for the specific language governing permissions and
 * limitations under the License.
 *
 *
 *  Created on: May 26, 2017
 *      Author: liebman
 */

#ifndef _SynchroClock_H_
#define _SynchroClock_H_
#include <Arduino.h>
#include <sys/time.h>
#include <ESP8266WiFi.h>
#include "ESP8266httpUpdate.h"
#include <WiFiManager.h>
#include <Wire.h>
#include <ESP8266WebServer.h>
#include <EEPROM.h>
#include "FeedbackLED.h"
#include "NTP.h"
#include "Clock.h"
#include "DS3231.h"
#include "WireUtils.h"
#include "TimeUtils.h"
#include "ConfigParam.h"
#include "Logger.h"
#include "DLogPrintWriter.h"
#include "DLogSyslogWriter.h"
#include <memory>
#include <vector>

#define USE_DRIFT                   // apply drift
#define USE_NTP_POLL_ESTIMATE       // use ntp estimated drift for sleep duration calculation
#define USE_STOP_THE_CLOCK          // if defined then stop the clock for small negative adjustments
#define STOP_THE_CLOCK_MAX     60   // maximum difference where we will use stop the clock
#define STOP_THE_CLOCK_EXTRA   2    // extra seconds to leave the clock stopped

// pin definitions
#define LED_PIN                13    // (GPIO13) LED on pin, active low
#define SYNC_PIN               14    // (GPIO14) pin tied to 1hz square wave from RTC
#define CONFIG_PIN             12    // (GPIO12) button tied to pin

#define DEFAULT_TZ_OFFSET      0     // default timzezone offset in seconds
#define DEFAULT_NTP_SERVER     "0.zoddotcom.pool.ntp.org"
#define DEFAULT_SLEEP_DURATION 28800 // default is 8hrs when we are not using the poll estimate

#define CLOCK_STRETCH_LIMIT    1500  // i2c clock stretch timeout in microseconds
#define MAX_SLEEP_DURATION     3600  // we do multiple sleep of this to handle bigger sleeps
#define CONNECTION_TIMEOUT     30    // wifi connection timeout - we will deep sleep and try again later
#define CONFIG_DELAY           1000  // how long to hold the button for config mode - light comes on after this time.
#define FACTORY_RESET_DELAY    10000 // how long to hold the button for factory reset after LED is ON - 10 seconds (10,000 milliseconds)

#define UPDATE_URL_FILENAME    "updateurl.txt"

#define offset2longDouble(x)   ((long double)x / 4294967296L)

// default time change definitions
#if !defined(DEFAULT_TC0_OCCUR) 
#warning "DEFAULT_TC0_OCCUR not configured!"
#define DEFAULT_TC0_OCCUR  1
#endif

#if !defined(DEFAULT_TC0_DOW)
#warning "DEFAULT_TC0_DOW not configured!"
#define DEFAULT_TC0_DOW    0
#endif

#if !defined(DEFAULT_TC0_DOFF)
#warning "DEFAULT_TC0_DOFF not configured!"
#define DEFAULT_TC0_DOFF   0
#endif

#if !defined(DEFAULT_TC0_MONTH)
#warning "DEFAULT_TC0_MONTH not configured!"
#define DEFAULT_TC0_MONTH  0
#endif

#if !defined(DEFAULT_TC0_HOUR)
#warning "DEFAULT_TC0_HOUR not configured!"
#define DEFAULT_TC0_HOUR   0
#endif

#if !defined(DEFAULT_TC0_OFFSET)
#warning "DEFAULT_TC0_OFFSET not configured!"
#define DEFAULT_TC0_OFFSET 0
#endif

#if !defined(DEFAULT_TC1_OCCUR)
#warning "DEFAULT_TC1_OCCUR not configured!"
#define DEFAULT_TC1_OCCUR  1
#endif

#if !defined(DEFAULT_TC1_DOW)
#warning "DEFAULT_TC1_DOW not configured!"
#define DEFAULT_TC1_DOW    0
#endif

#if !defined(DEFAULT_TC1_DOFF)
#warning "DEFAULT_TC1_DOFF not configured!"
#define DEFAULT_TC1_DOFF   0
#endif

#if !defined(DEFAULT_TC1_MONTH)
#warning "DEFAULT_TC1_MONTH not configured!"
#define DEFAULT_TC1_MONTH  0
#endif

#if !defined(DEFAULT_TC1_HOUR)
#warning "DEFAULT_TC1_HOUR not configured!"
#define DEFAULT_TC1_HOUR   0
#endif

#if !defined(DEFAULT_TC1_OFFSET)
#warning "DEFAULT_TC1_OFFSET not configured!"
#define DEFAULT_TC1_OFFSET 0
#endif

// error codes for setRTCfromNTP()
#define ERROR_DNS -1
#define ERROR_RTC -2
#define ERROR_NTP -3

#define TIME_CHANGE_COUNT  2

typedef struct config
{
    uint32_t   sleep_duration;           // deep sleep duration in seconds
    int        tz_offset;                // time offset in seconds from UTC
    uint16_t   syslog_port;              // port for network logging
    TimeChange tc[TIME_CHANGE_COUNT];    // time change description
    char       ntp_server[64];           // host to use for ntp
    char       syslog_host[64];          // host for network logging
    NTPPersist ntp_persist;              // ntp persisted data
} Config;

typedef struct ee_config
{
    uint32_t crc;
    uint8_t data[sizeof(Config)];
} EEConfig;

typedef struct deep_sleep_data
{
    uint32_t sleep_delay_left;          // number seconds still to sleep
    NTPRunTime ntp_runtime;             // NTP runtime data
    bool run_update;                    // do update if true
} DeepSleepData;

typedef struct rtc_deep_sleep_data
{
    uint32_t crc;
    uint8_t data[sizeof(DeepSleepData)];
} RTCDeepSleepData;

typedef std::shared_ptr<ConfigParam> ConfigParamPtr;
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

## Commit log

2017-03-23 Added start of schematic (its going to change a lot!)
    [SynchroClock.kicad_pcb, SynchroClock.sch]
2017-03-23 using atmega328 for now
    [SynchroClock.sch]
2017-03-25 use interrupt timers for ticks conditional on #define USE_TIMER
2017-03-25 always use timer/interrupts, remove USE_TIMER conditionals
2017-03-26 update schematic (WIP)
    [SynchroClock.sch]
2017-03-26 added diodes to drop clock output voltage
    [SynchroClock.sch]
2017-03-26 fixed origin timestamp, attempted to compute delay and offset (not working)
    [SynchroClock.cpp, SynchroClock.h]
2017-03-26 more schematic work
    [SynchroClock.sch]
2017-03-29 use 1.5v to drive clock - better timing 16ms tick pusles and an adjust delay of 8ms
    [SynchroClock.sch]
2017-03-31 compute NTP offset correctly
    [SynchroClock.cpp]
2017-03-31 use offset to set time, create dbug print macros instead of Serial.print*
2017-04-19 Fleshout circuit more
    [SynchroClock.kicad_pcb]
2017-04-20 v1 PCB layout
    [SynchroClock.kicad_pcb, SynchroClock.sch]
2017-04-23 lock in v0.1 kicad
    [SynchroClock.kicad_pcb, SynchroClock.sch]
2017-04-25 add interrupt/timer config for ATTiny85
2017-04-29 ATTiny85 - working sort of.... i2c hangs on first request after a write
2017-04-30 Cleanup - no longer need wire library wrapper since USIWire is compatable!
    [I2CAnalogClock.cpp, I2CAnalogClock.h]
2017-04-30 Use sleep to reduce power
2017-05-02 updated hardware design
    [SynchroClock.kicad_pcb, SynchroClock.sch]
2017-05-11 added old version new version updated a bit - still not done or compleatly tested
    [SynchroClock.dsn, SynchroClock.sch]
2017-05-13 dont include Eclipse files or fake .ino file when using Arduino IDE
2017-05-13 Fixed race conditions with position and adjustment value during adjustment
    [I2CAnalogClock.cpp]
2017-05-13 added sleep_delay to sleep DRV8838 to save power.
2017-05-14 use timer (not loop) for adjustment, now both tick and adjust are interrupt/timer driven always fire one tick on startup to sync clock motor
2017-05-14 no need to tick once on startup as I2CAnalogClock now does that
2017-05-14 use idle sleep for now (working on power down sleep)
2017-05-15 now power down the DRV8838 and the I2CAnalogClock MCU to save power (from 2.6ma+ to 0.74ma avg!!!) Converted the ATTiny85 reset pin to an output as I needed a pin for teh DRV disable!
2017-05-15 updated with reset & sleep changes
    [SynchroClock.sch]
2017-05-16 Version 0.2 of Board
    [SynchroClock.dsn, SynchroClock.kicad_pcb, SynchroClock.sch]
2017-05-26 new implementation to talk with DS3231 w/wire error checking added some wire error checking to Clock I2C bus Recovery method added via WireUtils
    [SynchroClock.cpp, SynchroClock.h]
2017-05-26 added error codes for netRTCfromNTP()
    [SynchroClock.cpp, SynchroClock.h]
2017-05-27 stability improvements and cleanup
    [SynchroClock.cpp, SynchroClock.h]
2017-06-04 If we wake with the reset button pressed and sleep_delay_left then the radio is off, use a deepSleep to turn it back on.
2017-06-04 added comment about short deep sleep
    [SynchroClock.cpp]
2017-06-06 Initial time change support - currently hardcoded to US/Pacific Rules.
2017-06-27 switch to eagle cad for hardware
    [SynchroClock.brd, SynchroClock.dsn, SynchroClock.kicad_pcb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]
2017-06-28 fixed the network logger port configuration
    [SynchroClock.cpp, SynchroClock.h]
2017-07-06 Switch offset to double, jitter calculations for observation.
    [NTP.h, SynchroClock.cpp, SynchroClock.h]
2017-07-14 major refactor of NTP code, now includes NTPTest framework to allow NTP debugging on MacOS/unix
2017-07-19 correct the mdelay calculation for negative offsets
    [SynchroClock.cpp]
2017-07-19 switch to 1.5v for clock voltage regulator
    [SynchroClock.brd, SynchroClock.sch]
2017-07-25 Updated NTP algo with drift. Still need to find a way to speed up initial sync and drift calculation.
    [NTP.h, SynchroClock.cpp, SynchroClock.h]
2017-07-29 tune threshold from 40ms to 20ms to compute drift faster
    [NTP.h]
2017-07-30 added schematic image
2017-09-01 Code now works with basic h bridge, now need to update the schematic/board
2017-09-09 no longer have to use stay awake logic, timeing still not right for AP duration/delay/duty
    [I2CAnalogClock.cpp, I2CAnalogClock.h, SynchroClock.cpp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]
2017-09-09 "development" version - board that does not have the clock driver
    [SynchroClock.brd, SynchroClock.sch]
2017-09-10 Working with PWM - basic tunings done
2017-09-12 correctly apply current clock settings if its running over the config, if its not running then the config wins
    [SynchroClock.cpp]
2017-09-12 removed un-needed non-PWM & DRV code
2017-09-12 cleanup to remove un-needed sleep delay as it was only used for the DRV motor controler
2017-09-13 minor cleanup / set current defaults in I2CAnalogClock
2017-09-14 Alpha 2.0 board
    [SynchroClock.brd, SynchroClock.sch]
2017-09-16 Updated for v2
    Now uses PWM for ticks (saves power)
    No longer using motor controller (also saves power)
2017-09-16 updated schematic for current Alpha version
2017-09-16 cleanup no longer needed debug options and small cleanups
    [I2CAnalogClock.cpp, I2CAnalogClock.h, NTP.h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]
2017-09-17 basic powerfail now works - still need to add more data to be saved
2017-09-17 added power fail circuit for ATtiny85 added BOM save all clock properties at power fail
    [SynchroClock.brd, SynchroClock.sch]
2017-09-18 updated schematic
2017-09-21 document attiny8 fuse settings set register with PWM_TOP so it can be changed
2017-09-24 added powerfail detection and saving of clock position and state (tick or tock & enababled or not) I2CAnalogClock (ATtiny) now has its config saved
2017-10-02 updated with new voltage regulator and pwrgd signal for power fail
    [SynchroClock.brd, SynchroClock.sch]
2017-10-07 board version 2.1
    [SynchroClock.brd, SynchroClock.sch]
2017-10-07 board 2.1a
    [SynchroClock.brd, SynchroClock.sch]
2017-10-08 updated schematic for readme
2018-03-21 added timezone info use actual pin numbers so we can use generic board
2018-03-22 fix "case" typo Dlog.h -> DLog.h
2018-03-25 Implement factory reset - resolves #10 Disable config ports in autoConnect - resolves #11
    Requires: https://github.com/tzapu/WiFiManager/pull/575
    [SynchroClock.cpp, SynchroClock.h]
2018-03-27 factory reset was very broken. Now working!
    [I2CAnalogClock.cpp, I2CAnalogClock.h, SynchroClock.cpp]
2018-03-28 log both versions on startup log clock reset reason & position on startup
    [I2CAnalogClock.cpp, I2CAnalogClock.h, SynchroClock.cpp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]
2018-04-05 use a modified fork of the arduino platformio framework to get updated ATTiny support
2018-04-05 dont need the hack anymore because we have a modified framework
2018-04-20 hold button for 1 second for config mode, 10 more seconds for factory reset
    [SynchroClock.cpp, SynchroClock.h]
2018-06-17 added syslg & cleanup SSID/Device name
    [SynchroClock.brd]
2018-12-21 adjust esp8266 device settings for updated core
2018-12-21 adjust esp8266 device settings for updated core some more
2019-07-16 switch to platformIO
2019-07-24 add platformio fuse setting and correct cpu freq for attiny85
2019-07-28 add workaround to prevent flash erase when using the platformio fuses target
2019-08-25 Fix filename in comment at top of file.
    [I2CAnalogClock.cpp]
2019-08-25 sync clock with RTC when WiFi connect fails in case of power outage where WiFi is not available
    [SynchroClock.cpp]
2019-08-30 started unit tests (its a work in progress) moved many file to include & lib for easy access from unit tests broke pin definitions out into a seperate include file for easy access from tests
    [DS3231Test.cpp, SynchroClock.h]
2019-09-06 - increase CLOCK_STRETCH_LIMIT - bump SynchroClock version to 1.1.6 - define NTP_REQUEST_COUNT in platformio.ini for >1 NTP req's per cycle when more than one NTP choose the lowest delay - fix warnin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
    [SynchroClock.cpp, SynchroClock.h]
2019-09-08 Add a 10ms delay to Syslog messages to hopefully loose less Use platform 2.2.3 Use defines for various intervals that can be overridden with compile options attemp to disable lwip ntp with sntp_serve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
    [SynchroClock.cpp]
2019-09-09 improve selection of samples for drift estimate by using same criteria as for selecting offisets to use. version 1.1.9
    [SynchroClock.cpp, SynchroClock.h]
2019-09-14 include pio env name in version string timestamps in samples now reflects new time and not time before offset adjustment don't include the initial first sample offset in estimated drift calculation S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
2019-09-18 bump version to 1.1.11 print current time (GMT) with timestamps 10 samples first sample set in 4 hours
2021-09-08 Update the repo to more modern toolchain (#21)
    * Update to Espressif8266 2.6.3 toolchain
    This necessitates the removal (temporarily, at least) of -Werror so we
    can complete a compilation successfully.
    * Update mkdata.py for Python 3
    Python 2.7 has been sunsetted since January 1, 2020. Update the builder
    to use Python 3.9 as it is the latest stable version.
    * Use GitHub Actions
    Since my balance went negative on Travis-CI, it has never built anything for me.
    Switch to GitHub Actions which works arguably better than Travis.
    * GitHub Actions: remove staging env
    The staging environment does not work, so remove it from CI for now.

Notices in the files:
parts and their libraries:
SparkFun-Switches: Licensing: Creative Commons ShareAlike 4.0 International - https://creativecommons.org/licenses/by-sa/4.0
